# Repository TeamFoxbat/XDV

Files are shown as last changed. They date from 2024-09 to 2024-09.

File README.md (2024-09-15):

# XDV
100% digital-to-digital video encoder inspired by existing projects for the Original Xbox. Currently no firmware released but is compatible with existing digital video encoding solutions.

## Installation Notes
The v1.0-1.4 Xbox boards have a big electrolytic cap next to the stock encoder that will interfere with installation. Recommendation is to replace with a S1206 10uF ceramic.

The ferite bead on the bottom right of the stock encoder must be removed. 

Notes for installing the power and SMBus harnesses to come soon.

## Status Update
The Rev B board (not available here) does successfully take MakeMHz XboxHD+ firmware but has some visual glitches likely due to the flex PCB (not publicly available yet). Further work needs to be done to determine the cause but it's likely the flex.

The Rev C offers some minor improvements to reduce impedence mismatch on the TMDS traces but has not been ordered, a minor improvement to get closer to the spec.

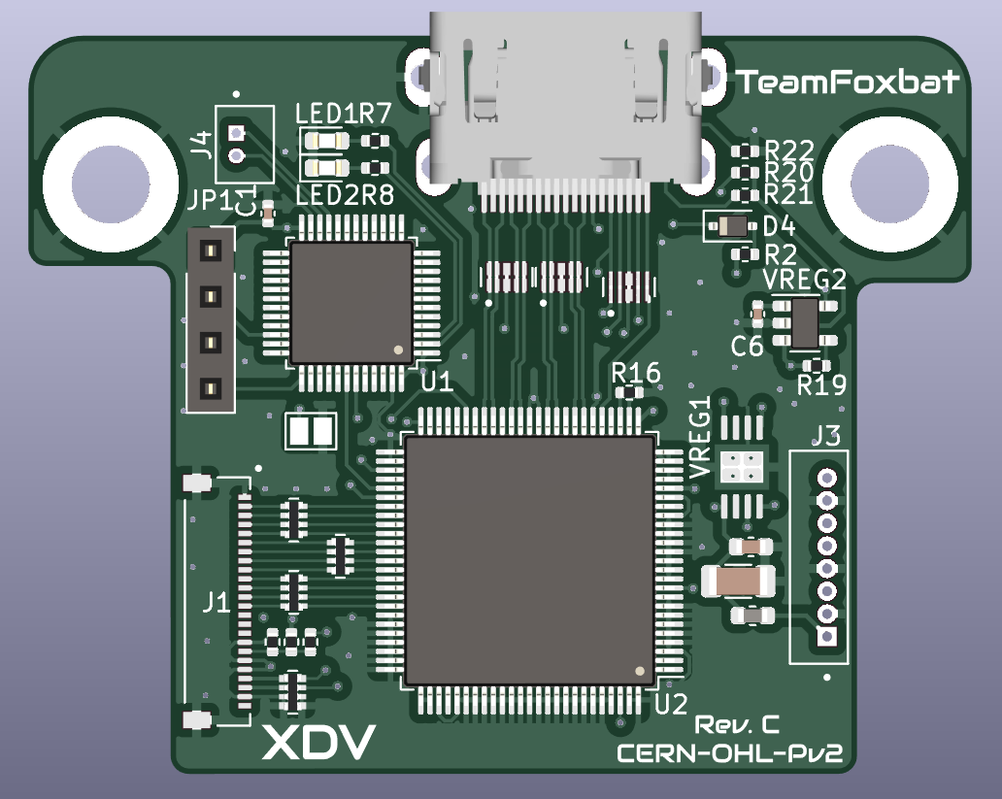
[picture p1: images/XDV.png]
partial 3D render


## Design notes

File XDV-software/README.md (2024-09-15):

Hardware likely compatible with both the Ryzee119 XboxHDMI firmware (and subsequent designs) with some small modifications for pin placement. Also compatible with MakeMHz XboxHDMI/XboxHD+ firmware. Currently untested for now.

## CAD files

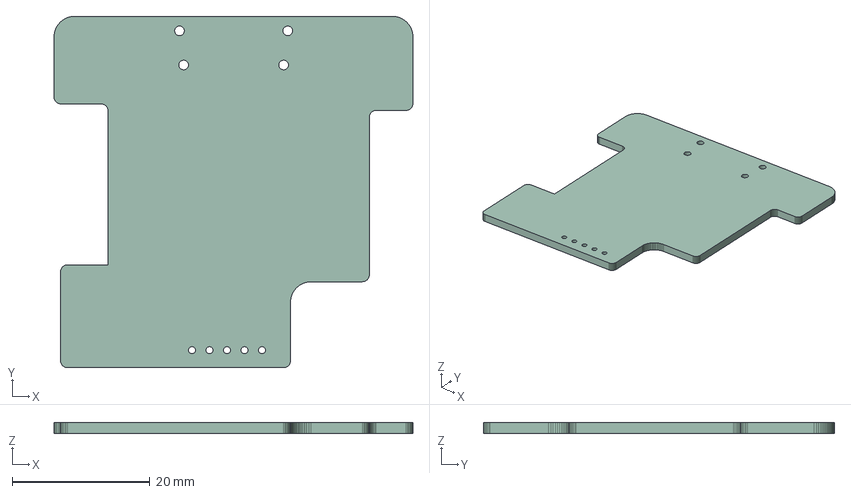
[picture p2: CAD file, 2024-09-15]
XDV-hardware/XDV.step
52.1 x 51.0 x 1.60 mm

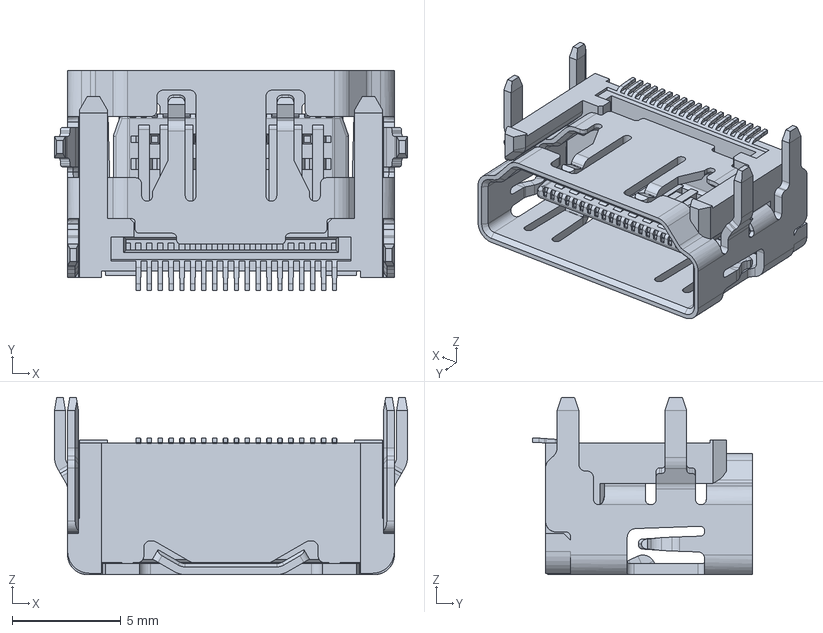
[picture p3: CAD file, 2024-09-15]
XDV-hardware/10029449-111RLF.stp
16.2 x 10.1 x 8.13 mm

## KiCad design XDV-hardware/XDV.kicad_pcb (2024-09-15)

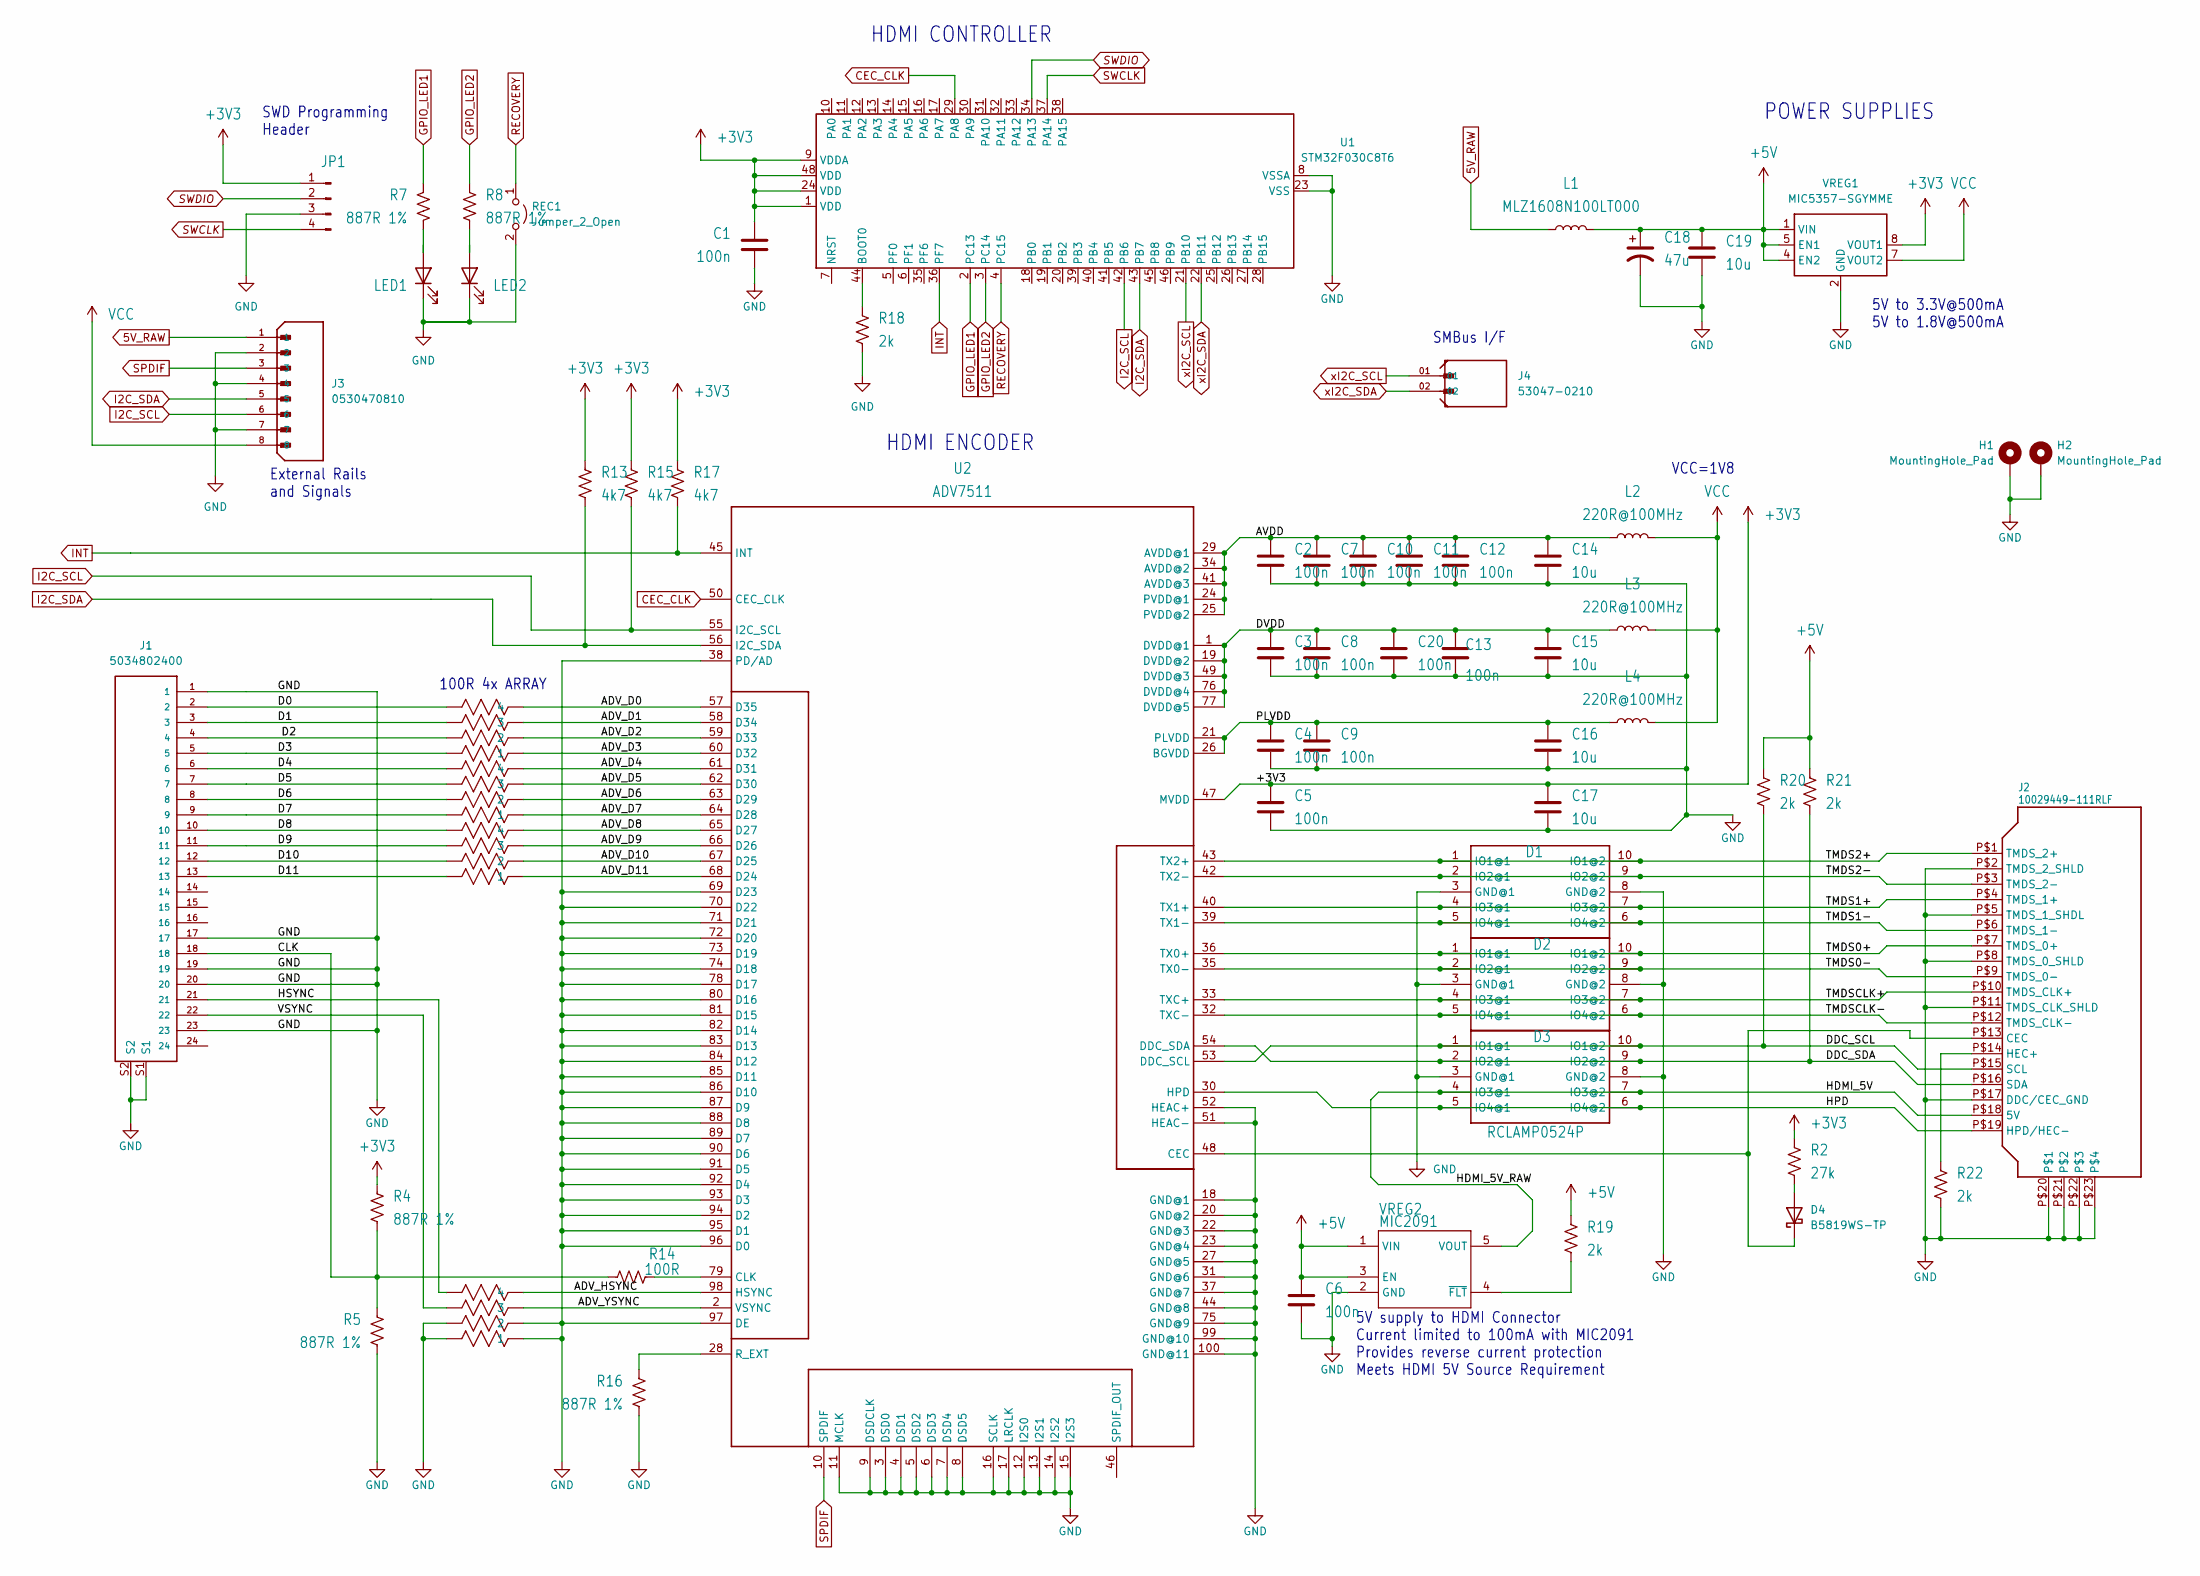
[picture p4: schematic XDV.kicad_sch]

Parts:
C1, C2, C3, C4, C5, C6, C7, C8, C9, C10, C11, C12, C13, C20: 100n; C_0402_1005Metric
C14, C15, C16, C17, C19: 10u; C_0603_1608Metric
C18: 47u; C_1206_3216Metric
D1, D2, D3: RCLAMP0524P; DIO_RCLAMP0524PATCT
D4: B5819WS-TP; D_SOD-323
H1, H2: MountingHole_Pad; MountingHole_4.3mm_M4_DIN965_Pad_TopBottom
J1: 5034802400; MOLEX_5034802400; PARTREV J
J2: 10029449-111RLF; HDMI_10029449
J3: 0530470810; MOLEX_0530470810; PARTREV B
J4: 53047-0210; MOLEX_53047-0210; PARTREV 04/19/2022
JP1: PINHD-1X5; PinSocket_1x04_P2.54mm_Vertical
L1: MLZ1608N100LT000; L_0603_1608Metric
L2, L3, L4: 220R@100MHz; L_0603_1608Metric
LED1: 150060VS75000; LED_0603_1608Metric
LED2: 150060BS75000; LED_0603_1608Metric
R2: 27k; R_0402_1005Metric
R4, R5, R7, R8, R16: 887R 1%; R_0402_1005Metric
R9, R10, R11, R12: YC124-JR-0733RL; R_Array_Convex_4x0402
R13, R15, R17: 4k7; R_0402_1005Metric
R14: 100R; R_0402_1005Metric
R18, R19, R20, R21, R22: 2k; R_0402_1005Metric
REC1: Jumper_2_Open; SolderJumper-2_P1.3mm_Open_Pad1.0x1.5mm
U1: STM32F030C8T6; LQFP-48_7x7mm_P0.5mm
U2: ADV7511; LQFP-100_14x14mm_P0.5mm
VREG1: MIC5357-SGYMME; MSOP-8-1EP_3x3mm_P0.65mm_EP2.5x3mm_Mask1.73x2.36mm_ThermalV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
VREG2: MIC2091; SOT-23-5

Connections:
5V_RAW: J3.1, L1.1
+3.3V: C1.1, C5.1, C17.1, JP1.1, R2.2, R4.2, R13.2, R15.2, R17.2, U1.1 (VDD), U1.9 (VDDA), U1.24 (VDD), U1.48 (VDD), U2.47 (MVDD), VREG1.8 (VOUT1)
+5V: C6.1, C18.1, C19.1, L1.2, R19.2, R20.2, R21.2, VREG1.1 (VIN), VREG1.4 (EN2), VREG1.5 (EN1), VREG2.1 (VIN), VREG2.3 (EN)
/ADV_D0: R9.4, U2.57 (D35)
/ADV_D1: R9.3, U2.58 (D34)
/ADV_D2: R9.2, U2.59 (D33)
/ADV_D3: R9.1, U2.60 (D32)
/ADV_D4: R10.4, U2.61 (D31)
/ADV_D5: R10.3, U2.62 (D30)
/ADV_D6: R10.2, U2.63 (D29)
/ADV_D7: R10.1, U2.64 (D28)
/ADV_D8: R11.4, U2.65 (D27)
/ADV_D9: R11.3, U2.66 (D26)
/ADV_D10: R11.2, U2.67 (D25)
/ADV_D11: R11.1, U2.68 (D24)
/ADV_HSYNC: R12.4, U2.98 (HSYNC)
/ADV_YSYNC: R12.3, U2.2 (VSYNC)
/AVDD: C2.1, C7.1, C10.1, C11.1, C12.1, C14.1, L2.1, U2.24 (PVDD@1), U2.25 (PVDD@2), U2.29 (AVDD@1), U2.34 (AVDD@2), U2.41 (AVDD@3)
/CLK: J1.18, R4.1, R5.2, R14.2
/D0: J1.2, R9.5
/D1: J1.3, R9.6
/D2: J1.4, R9.7
/D3: J1.5, R9.8
/D4: J1.6, R10.5
/D5: J1.7, R10.6
/D6: J1.8, R10.7
/D7: J1.9, R10.8
/D8: J1.10, R11.5
/D9: J1.11, R11.6
/D10: J1.12, R11.7
/D11: J1.13, R11.8
/DDC_SCL: D3.1 (IO1@1), D3.10 (IO1@2), J2.P$15 (SCL), R20.1, U2.53 (DDC_SCL)
/DDC_SDA: D3.2 (IO2@1), D3.9 (IO2@2), J2.P$16 (SDA), R21.1, U2.54 (DDC_SDA)
/DVDD: C3.1, C8.1, C13.1, C15.1, C20.1, L3.1, U2.1 (DVDD@1), U2.19 (DVDD@2), U2.49 (DVDD@3), U2.76 (DVDD@4), U2.77 (DVDD@5)
/HDMI_5V: D3.4 (IO3@1), D3.7 (IO3@2), J2.P$18 (5V), VREG2.5 (VOUT)
/HPD: D3.5 (IO4@1), D3.6 (IO4@2), J2.P$19 (HPD/HEC-), U2.30 (HPD)
/HSYNC: J1.21, R12.5
/PLVDD: C4.1, C9.1, C16.1, L4.1, U2.21 (PLVDD), U2.26 (BGVDD)
/TMDS0+: D2.1 (IO1@1), D2.10 (IO1@2), J2.P$7 (TMDS_0+), U2.36 (TX0+)
/TMDS0-: D2.2 (IO2@1), D2.9 (IO2@2), J2.P$9 (TMDS_0-), U2.35 (TX0-)
/TMDS1+: D1.4 (IO3@1), D1.7 (IO3@2), J2.P$4 (TMDS_1+), U2.40 (TX1+)
/TMDS1-: D1.5 (IO4@1), D1.6 (IO4@2), J2.P$6 (TMDS_1-), U2.39 (TX1-)
/TMDS2+: D1.1 (IO1@1), D1.10 (IO1@2), J2.P$1 (TMDS_2+), U2.43 (TX2+)
/TMDS2-: D1.2 (IO2@1), D1.9 (IO2@2), J2.P$3 (TMDS_2-), U2.42 (TX2-)
/TMDSCLK+: D2.4 (IO3@1), D2.7 (IO3@2), J2.P$10 (TMDS_CLK+), U2.33 (TXC+)
/TMDSCLK-: D2.5 (IO4@1), D2.6 (IO4@2), J2.P$12 (TMDS_CLK-), U2.32 (TXC-)
/VSYNC: J1.22, R12.6
CEC_CLK: U1.29 (PA8), U2.50 (CEC_CLK)
GND: C1.2, C2.2, C3.2, C4.2, C5.2, C6.2, C7.2, C8.2, C9.2, C10.2, C11.2, C12.2, C13.2, C14.2, C15.2, C16.2, C17.2, C18.2, C19.2, C20.2, D1.3 (GND@1), D1.8 (GND@2), D2.3 (GND@1), D2.8 (GND@2), D3.3 (GND@1), D3.8 (GND@2), H1.1, H2.1, J1.1, J1.17, J1.19, J1.20, J1.23, J1.S1, J1.S2, J2.P$2 (TMDS_2_SHLD), J2.P$5 (TMDS_1_SHDL), J2.P$8 (TMDS_0_SHLD), J2.P$11 (TMDS_CLK_SHLD), J2.P$17 (DDC/CEC_GND), J2.P$20, J2.P$21, J2.P$22, J2.P$23, J3.2, J3.4, J3.7, JP1.3, LED1.1 (K), LED2.1 (K), R5.1, R12.1, R12.2, R12.7, R12.8, R16.1, R18.1, R22.1, REC1.2 (B), U1.8 (VSSA), U1.23 (VSS), U1.47 (VSS), U2.3 (DSD0), U2.4 (DSD1), U2.5 (DSD2), U2.6 (DSD3), U2.7 (DSD4), U2.8 (DSD5), U2.9 (DSDCLK), U2.11 (MCLK), U2.12 (I2S0), U2.13 (I2S1), U2.14 (I2S2), U2.15 (I2S3), U2.16 (SCLK), U2.17 (LRCLK), U2.18 (GND@1), U2.20 (GND@2), U2.22 (GND@3), U2.23 (GND@4), U2.27 (GND@5), U2.31 (GND@6), U2.37 (GND@7), U2.38 (PD/AD), U2.44 (GND@8), U2.51 (HEAC-), U2.52 (HEAC+), U2.69 (D23), U2.70 (D22), U2.71 (D21), U2.72 (D20), U2.73 (D19), U2.74 (D18), U2.75 (GND@9), U2.78 (D17), U2.80 (D16), U2.81 (D15), U2.82 (D14), U2.83 (D13), U2.84 (D12), U2.85 (D11), U2.86 (D10), U2.87 (D9), U2.88 (D8), U2.89 (D7), U2.90 (D6), U2.91 (D5), U2.92 (D4), U2.93 (D3), U2.94 (D2), U2.95 (D1), U2.96 (D0), U2.97 (DE), U2.99 (GND@10), U2.100 (GND@11), VREG1.2 (GND), VREG1.9 (GND), VREG2.2 (GND)
GPIO_LED1: R7.2, U1.2 (PC13)
GPIO_LED2: R8.2, U1.3 (PC14)
I2C_SCL: J3.6, R15.1, U1.42 (PB6), U2.55 (I2C_SCL)
I2C_SDA: J3.5, R13.1, U1.43 (PB7), U2.56 (I2C_SDA)
INT: R17.1, U1.36 (PF7), U2.45 (INT)
unnamed: D4.2 (A), R2.1
unnamed: D4.1 (K), J2.P$13 (CEC), U2.48 (CEC)
unnamed: J2.P$14 (HEC+), R22.2
unnamed: LED1.2 (A), R7.1
unnamed: LED2.2 (A), R8.1
unnamed: R18.2, U1.44 (BOOT0)
unnamed: R14.1, U2.79 (CLK)
unnamed: R16.2, U2.28 (R_EXT)
unnamed: R19.1, VREG2.4 (~FLT)
RECOVERY: REC1.1 (A), U1.4 (PC15)
SPDIF: J3.3, U2.10 (SPDIF)
SWCLK: JP1.4, U1.37 (PA14)
SWDIO: JP1.2, U1.34 (PA13)
VCC: J3.8, L2.2, L3.2, L4.2, VREG1.7 (VOUT2)
xI2C_SCL: J4.01, U1.21 (PB10)
xI2C_SDA: J4.02, U1.22 (PB11)

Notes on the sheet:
5V supply to HDMI Connector Current limited to 100mA with MIC2091 Provides reverse current protection Meets HDMI 5V Source Requirement
VCC=1V8
SMBus I/F
HDMI CONTROLLER
POWER SUPPLIES
100R 4x ARRAY
5V to 3.3V@500mA 5V to 1.8V@500mA
HDMI ENCODER
SWD Programming Header
External Rails and Signals

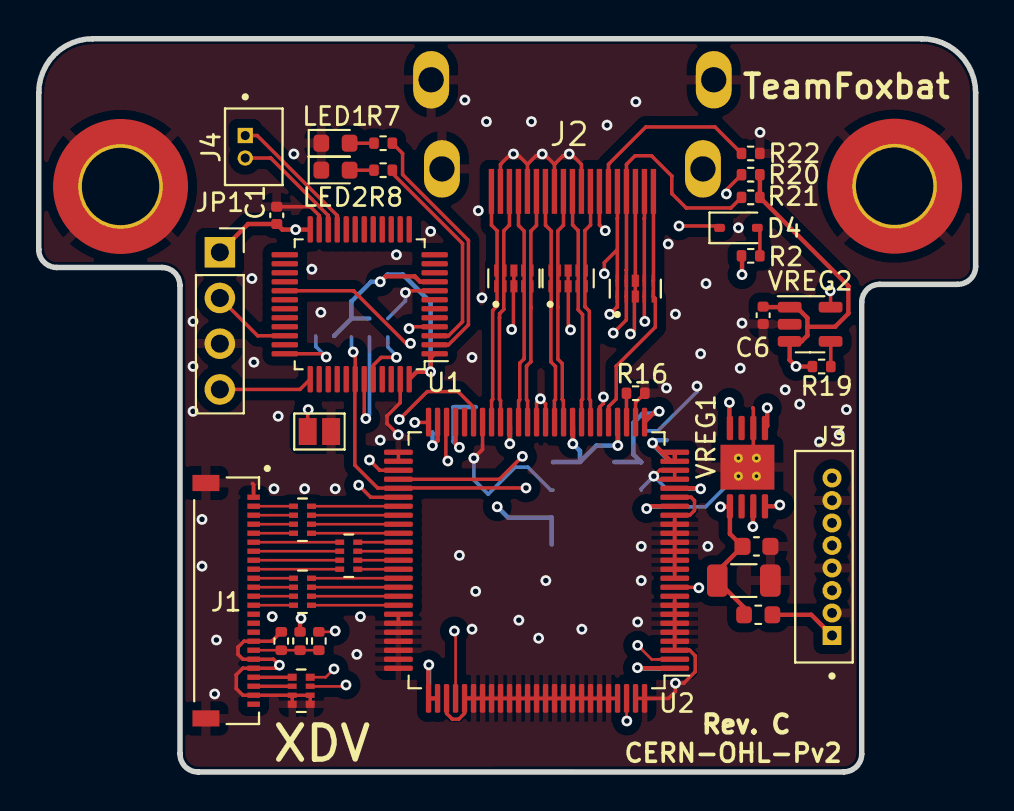
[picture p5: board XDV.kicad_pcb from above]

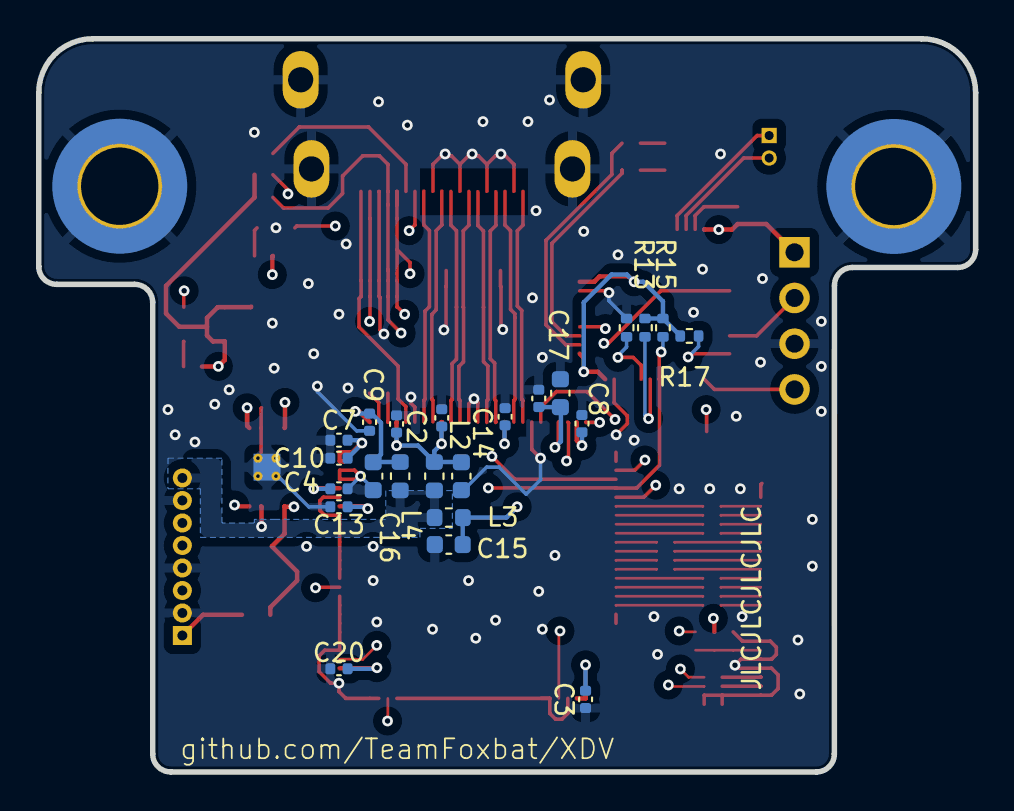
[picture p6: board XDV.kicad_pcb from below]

Board: 4 copper layers, 52.1 x 40.7 mm, 61 parts (23 on the bottom side), 70 nets.

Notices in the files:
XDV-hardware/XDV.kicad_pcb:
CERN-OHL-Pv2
